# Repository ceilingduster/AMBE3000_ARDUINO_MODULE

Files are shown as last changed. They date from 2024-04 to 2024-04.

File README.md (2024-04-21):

# AMBE3000 Arduino Module in KiCad 8
A PCB containing a DVSI AMBE-3000R (or AMBE-3003) Vocoders for use with WebSDRs/Audio transcoding.

This board is based on the design by George Smart, M1GEO and Chris Smart, G8OCV.

The DVSI AMBE parts can be purchased in low volume from the [DVSI Inc. Hardware Product Pricing](https://www.dvsinc.com/products/price.shtml) page. You will need to create a purchase order to buy from DVSI.

# Assembly

The design schematic include details for [JLCPCB](https://jlcpcb.com/) assembly, who assembled mine. You'll likely have to reflow the DVSI AMBE-3000R part yourself, which I did with a PCB reflow hotplate, but you can do any way you wish.

Each schematic component has a [JLCPCB Parts](https://jlcpcb.com/parts)/[LCSC](https://www.lcsc.com/) part number (Cxxxxxx), which can be exported to the BoM using the extra field "LCSC".

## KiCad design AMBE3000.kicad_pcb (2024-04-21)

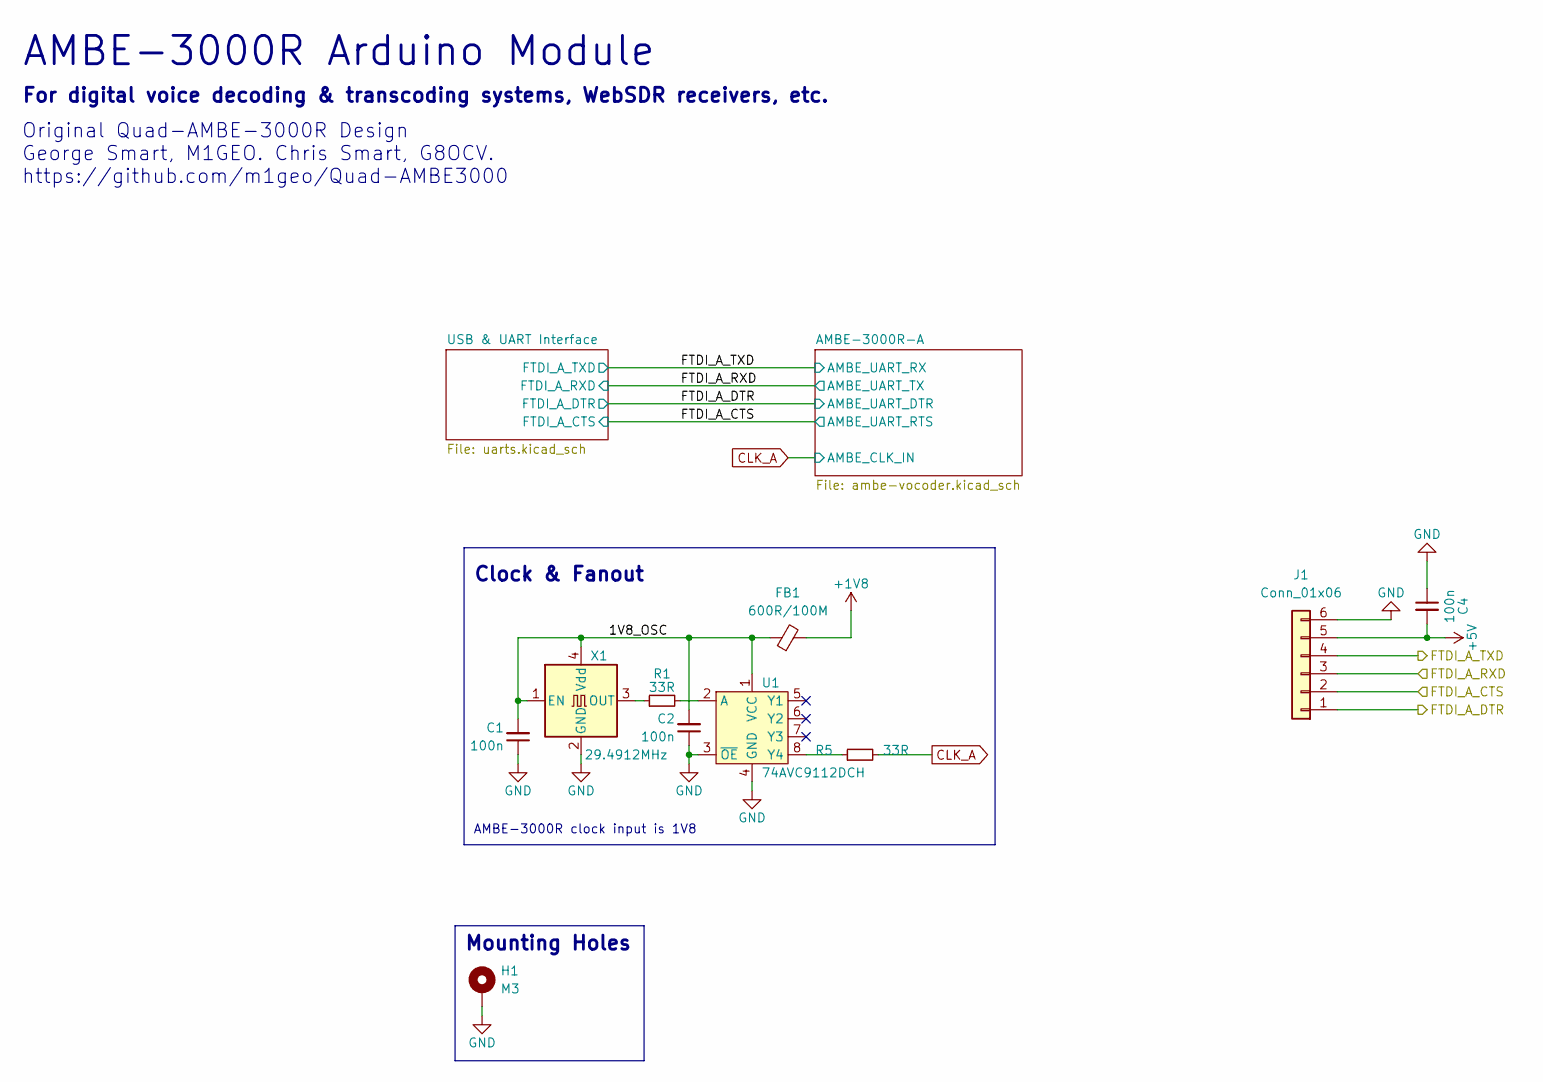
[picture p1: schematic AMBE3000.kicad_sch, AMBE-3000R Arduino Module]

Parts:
C1, C2, C4: 100n; C_0603_1608Metric; LCSC C14663
FB1: 600R/100M; L_0805_2012Metric; LCSC C1017
H1: M3; MountingHole_3.2mm_M3_Pad_Via; LCSC DNF
J1: Conn_01x06; PinHeader_1x06_P2.54mm_Vertical
R1, R5: 33R; R_0603_1608Metric; LCSC C23140
U1: 74AVC9112DCH; VSSOP-8_2.4x2.1mm_P0.5mm; LCSC C546283
X1: 29.4912MHz; Oscillator_SMD_Abracon_ASV-4Pin_7.0x5.1mm; LCSC C2901492

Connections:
+1V8: FB1.2; also elsewhere on the board
+5V: C4.2, J1.5; also elsewhere on the board
/1V8_OSC: C1.2, C2.2, FB1.1, U1.1 (VCC), X1.1 (EN), X1.4 (Vdd)
/FTDI_A_CTS: J1.2; also elsewhere on the board
/FTDI_A_DTR: J1.1; also elsewhere on the board
/FTDI_A_RXD: J1.3; also elsewhere on the board
/FTDI_A_TXD: J1.4; also elsewhere on the board
CLK_A: R5.2; also elsewhere on the board
GND: C1.1, C2.1, C4.1, H1.1, J1.6, U1.3 (~OE), U1.4 (GND), X1.2 (GND); also elsewhere on the board
unnamed: R1.2, U1.2 (A)
unnamed: R5.1, U1.8 (Y4)
unnamed: R1.1, X1.3 (OUT)

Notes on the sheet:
Original Quad-AMBE-3000R Design George Smart, M1GEO. Chris Smart, G8OCV. https://github.com/m1geo/Quad-AMBE3000
Mounting Holes
AMBE-3000R Arduino Module
AMBE-3000R clock input is 1V8
For digital voice decoding & transcoding systems, WebSDR receivers, etc.
Clock & Fanout

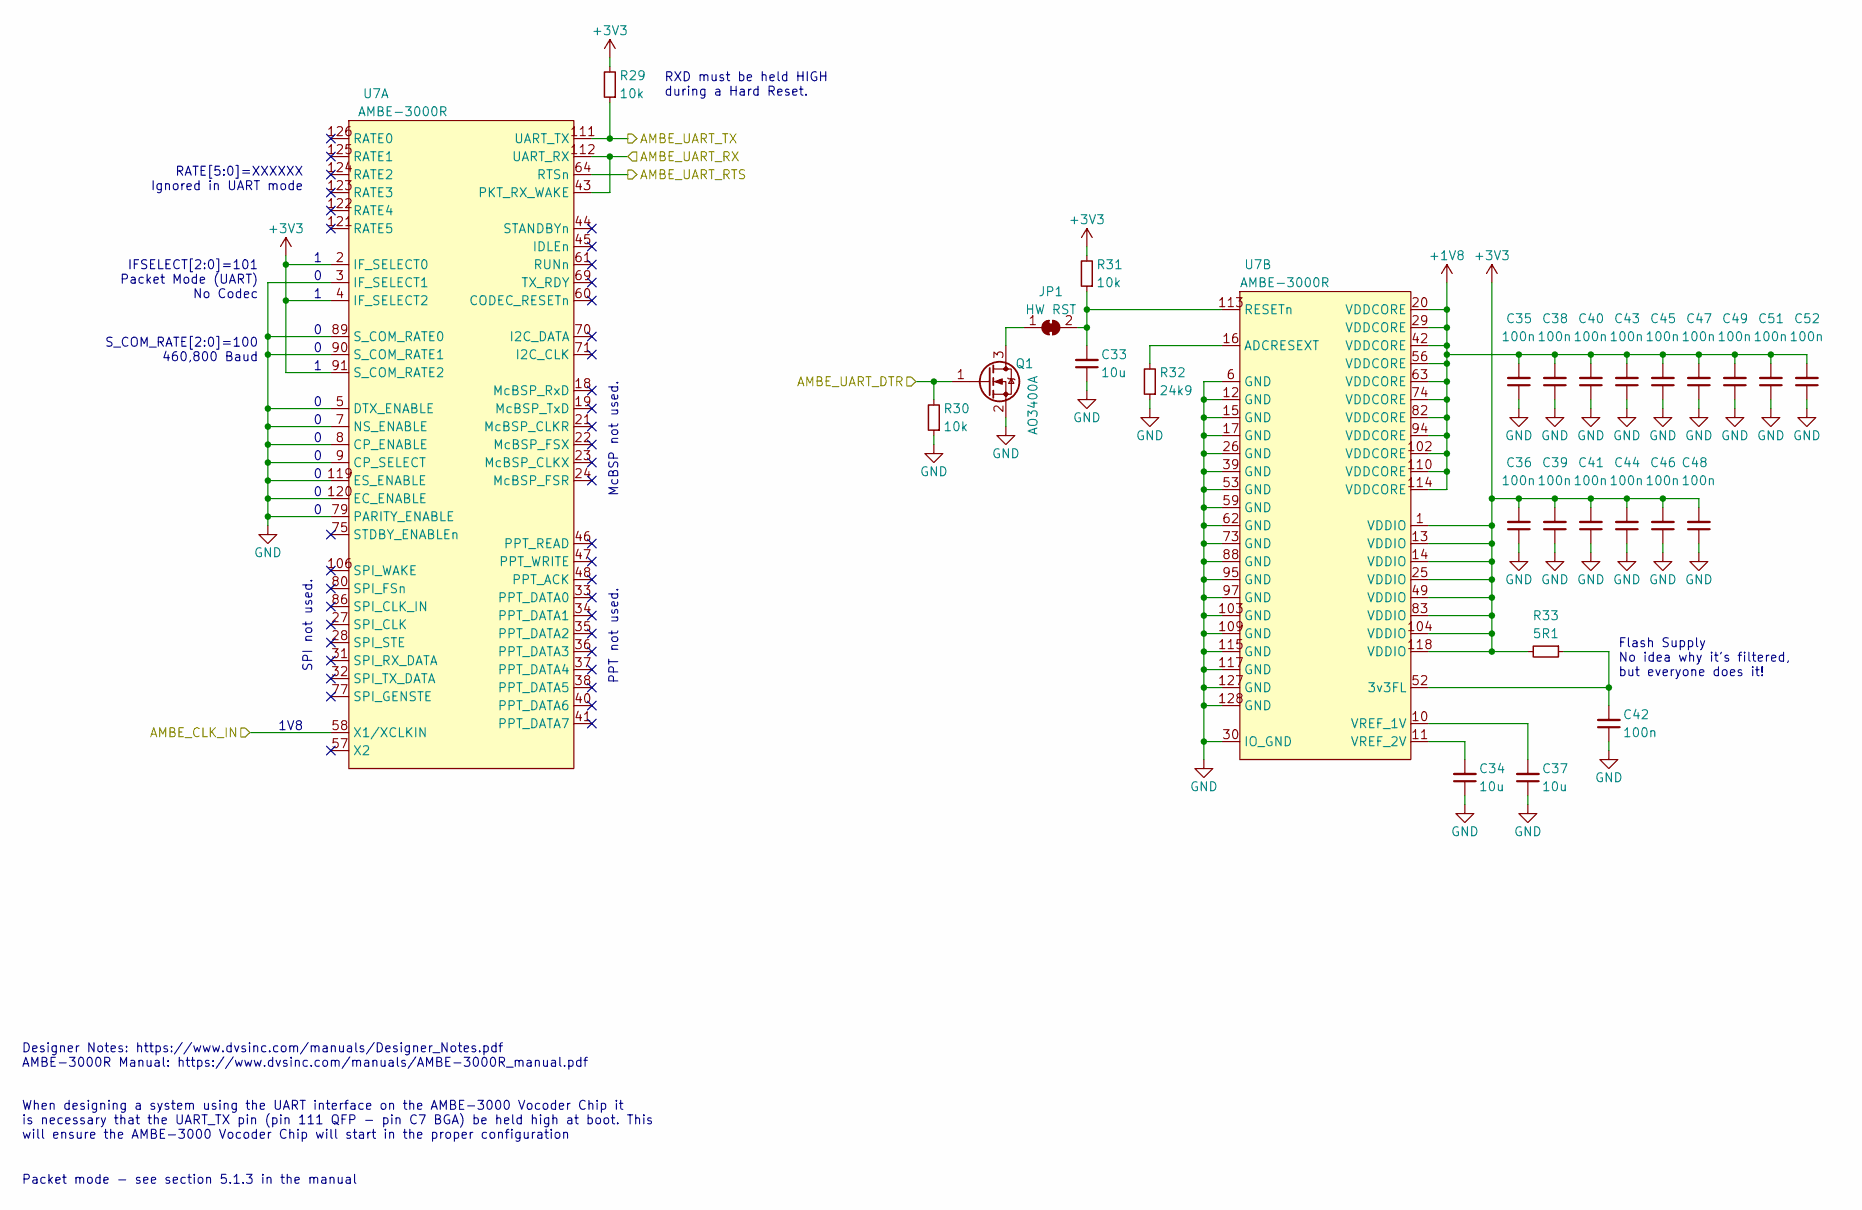
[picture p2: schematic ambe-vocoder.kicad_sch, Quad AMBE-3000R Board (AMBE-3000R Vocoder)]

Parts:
C33, C34, C37: 10u; C_0603_1608Metric; LCSC C19702
C35, C36, C38, C39, C40, C41, C42, C43, C44, C45, C46, C47, C48, C49, C51, C52: 100n; C_0603_1608Metric; LCSC C14663
JP1: HW RST; SolderJumper-2_P1.3mm_Open_RoundedPad1.0x1.5mm; LCSC DNF
Q1: AO3400A; SOT-23; LCSC C20917
R29, R30, R31: 10k; R_0603_1608Metric; LCSC C25804
R32: 24k9; R_0603_1608Metric; LCSC C25962
R33: 5R1; R_0603_1608Metric; LCSC C25197
U7: AMBE-3000R; LQFP-128_14x14mm_P0.4mm; LCSC DNF

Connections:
+1V8: C35.2, C38.2, C40.2, C43.2, C45.2, C47.2, C49.2, C51.2, C52.2, U7.20 (VDDCORE), U7.29 (VDDCORE), U7.42 (VDDCORE), U7.56 (VDDCORE), U7.63 (VDDCORE), U7.74 (VDDCORE), U7.82 (VDDCORE), U7.94 (VDDCORE), U7.102 (VDDCORE), U7.110 (VDDCORE), U7.114 (VDDCORE); also elsewhere on the board
+3V3: C36.2, C39.2, C41.2, C44.2, C46.2, C48.2, R29.2, R31.2, R33.2, U7.1 (VDDIO), U7.2 (IF_SELECT0), U7.4 (IF_SELECT2), U7.13 (VDDIO), U7.14 (VDDIO), U7.25 (VDDIO), U7.49 (VDDIO), U7.83 (VDDIO), U7.91 (S_COM_RATE2), U7.104 (VDDIO), U7.118 (VDDIO); also elsewhere on the board
/FTDI_A_CTS: U7.64 (RTSn); also elsewhere on the board
/FTDI_A_DTR: Q1.1 (G), R30.2; also elsewhere on the board
/FTDI_A_RXD: R29.1, U7.111 (UART_TX); also elsewhere on the board
/FTDI_A_TXD: U7.43 (PKT_RX_WAKE), U7.112 (UART_RX); also elsewhere on the board
CLK_A: U7.58 (X1/XCLKIN); also elsewhere on the board
GND: C33.1, C34.1, C35.1, C36.1, C37.1, C38.1, C39.1, C40.1, C41.1, C42.1, C43.1, C44.1, C45.1, C46.1, C47.1, C48.1, C49.1, C51.1, C52.1, Q1.2 (S), R30.1, R32.1, U7.3 (IF_SELECT1), U7.5 (DTX_ENABLE), U7.6 (GND), U7.7 (NS_ENABLE), U7.8 (CP_ENABLE), U7.9 (CP_SELECT), U7.12 (GND), U7.15 (GND), U7.17 (GND), U7.26 (GND), U7.30 (IO_GND), U7.39 (GND), U7.53 (GND), U7.59 (GND), U7.62 (GND), U7.73 (GND), U7.79 (PARITY_ENABLE), U7.88 (GND), U7.89 (S_COM_RATE0), U7.90 (S_COM_RATE1), U7.95 (GND), U7.97 (GND), U7.103 (GND), U7.109 (GND), U7.115 (GND), U7.117 (GND), U7.119 (ES_ENABLE), U7.120 (EC_ENABLE), U7.127 (GND), U7.128 (GND); also elsewhere on the board
unnamed: JP1.1 (A), Q1.3 (D)
unnamed: C33.2, JP1.2 (B), R31.1, U7.113 (RESETn)
unnamed: C42.2, R33.1, U7.52 (3v3FL)
unnamed: R32.2, U7.16 (ADCRESEXT)
unnamed: C37.2, U7.10 (VREF_1V)
unnamed: C34.2, U7.11 (VREF_2V)

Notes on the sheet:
1V8
IFSELECT[2:0]=101 Packet Mode (UART) No Codec
McBSP not used.
RATE[5:0]=XXXXXX Ignored in UART mode
Packet mode - see section 5.1.3 in the manual
Designer Notes: https://www.dvsinc.com/manuals/Designer_Notes.pdf AMBE-3000R Manual: https://www.dvsinc.com/manuals/AMBE-3000R_manual.pdf
S_COM_RATE[2:0]=100 460,800 Baud
PPT not used.
Flash Supply No idea why it's filtered, but everyone does it!
SPI not used.
RXD must be held HIGH during a Hard Reset.
When designing a system using the UART interface on the AMBE-3000 Vocoder Chip it is necessary that the UART_TX pin (pin 111 QFP - pin C7 BGA) be held high at boot. This will ensure the AMBE-3000 Vocoder Chip will start in the proper configuration

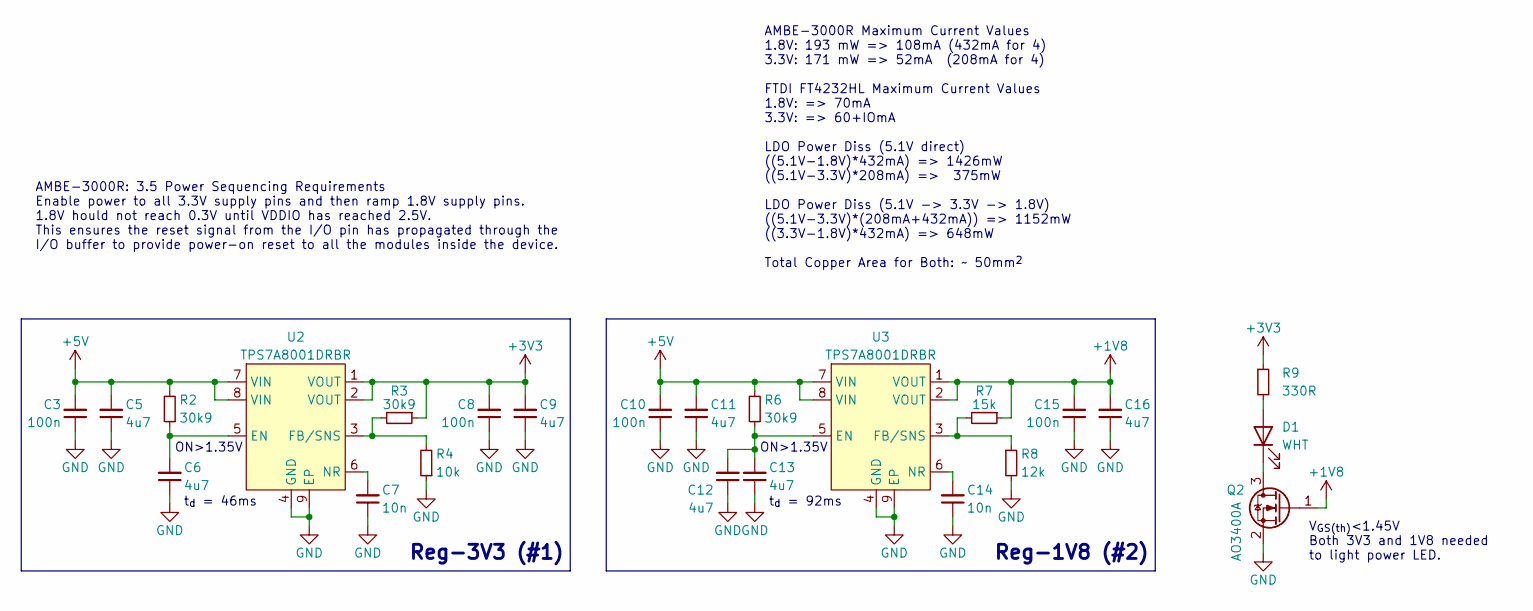
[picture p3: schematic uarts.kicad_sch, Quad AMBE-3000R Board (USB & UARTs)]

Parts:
C3, C8, C10, C15: 100n; C_0603_1608Metric; LCSC C14663
C5, C6, C9, C11, C12, C13, C16: 4u7; C_0603_1608Metric; LCSC C19666
C7, C14: 10n; C_0603_1608Metric; LCSC C57112
D1: WHT; LED_0603_1608Metric; LCSC C2290
Q2: AO3400A; SOT-23; LCSC C20917
R2, R3, R6: 30k9; R_0603_1608Metric; LCSC C217957
R4: 10k; R_0603_1608Metric; LCSC C25804
R7: 15k; R_0603_1608Metric; LCSC C22809
R8: 12k; R_0603_1608Metric; LCSC C22790
R9: 330R; R_0603_1608Metric; LCSC C23138
U2, U3: TPS7A8001DRBR; Texas_DRB0008A; LCSC C105265

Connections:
+1V8: C15.2, C16.2, Q2.1 (G), R7.1, U3.1 (VOUT), U3.2 (VOUT); also elsewhere on the board
+3V3: C8.2, C9.2, R3.1, R9.1, U2.1 (VOUT), U2.2 (VOUT); also elsewhere on the board
+5V: C3.2, C5.2, C10.2, C11.2, R2.2, R6.2, U2.7 (VIN), U2.8 (VIN), U3.7 (VIN), U3.8 (VIN); also elsewhere on the board
GND: C3.1, C5.1, C6.1, C7.1, C8.1, C9.1, C10.1, C11.1, C12.1, C13.1, C14.1, C15.1, C16.1, Q2.2 (S), R4.1, R8.2, U2.4 (GND), U2.9 (EP), U3.4 (GND), U3.9 (EP); also elsewhere on the board
unnamed: D1.2 (A), R9.2
unnamed: D1.1 (K), Q2.3 (D)
unnamed: C6.2, R2.1, U2.5 (EN)
unnamed: R3.2, R4.2, U2.3 (FB/SNS)
unnamed: C7.2, U2.6 (NR)
unnamed: C12.2, C13.2, R6.1, U3.5 (EN)
unnamed: R7.2, R8.1, U3.3 (FB/SNS)
unnamed: C14.2, U3.6 (NR)

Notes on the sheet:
Reg-1V8 (#2)
V_{GS(th)}<1.45V Both 3V3 and 1V8 needed to light power LED.
ON>1.35V
t_{d} = 92ms
Reg-3V3 (#1)
AMBE-3000R Maximum Current Values 1.8V: 193 mW => 108mA (432mA for 4) 3.3V: 171 mW => 52mA (208mA for 4) FTDI FT4232HL Maximum Current Values 1.8V: => 70mA 3.3V: => 60+IOmA LDO Power Diss (5.1V direct) ((5.1V-1.8V)*432mA) => 1426mW ((5.1V-3.3V)*208mA) => 375mW LDO Power Diss (5.1V -> 3.3V -> 1.8V) 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
t_{d} = 46ms
AMBE-3000R: 3.5 Power Sequencing Requirements Enable power to all 3.3V supply pins and then ramp 1.8V supply pins. 1.8V hould not reach 0.3V until VDDIO has reached 2.5V. This ensures the reset signal from the I/O pin has propagated through the I/O buffer to provide power-on reset to all the module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

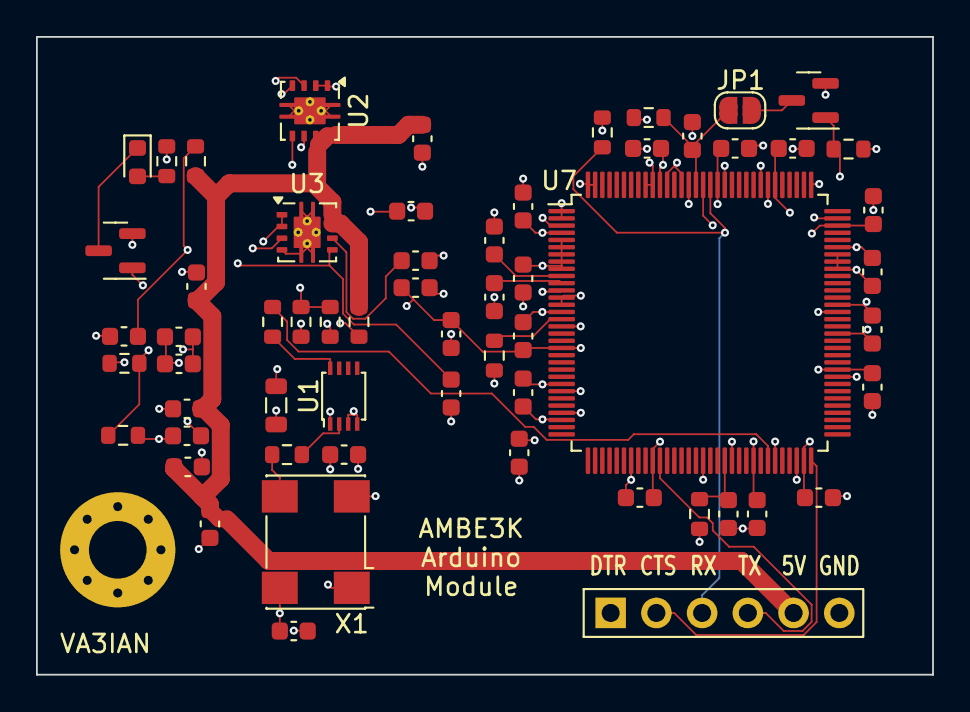
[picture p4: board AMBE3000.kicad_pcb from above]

Board: 4 copper layers, 49.8 x 35.4 mm, 61 parts (0 on the bottom side), 27 nets.
